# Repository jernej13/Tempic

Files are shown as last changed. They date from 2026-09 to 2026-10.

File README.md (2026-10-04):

# Tempic
Small 50mm x 50mm solar powered ESP32c6 based indoor/outdoor WiFi/Zigbee sensor node.

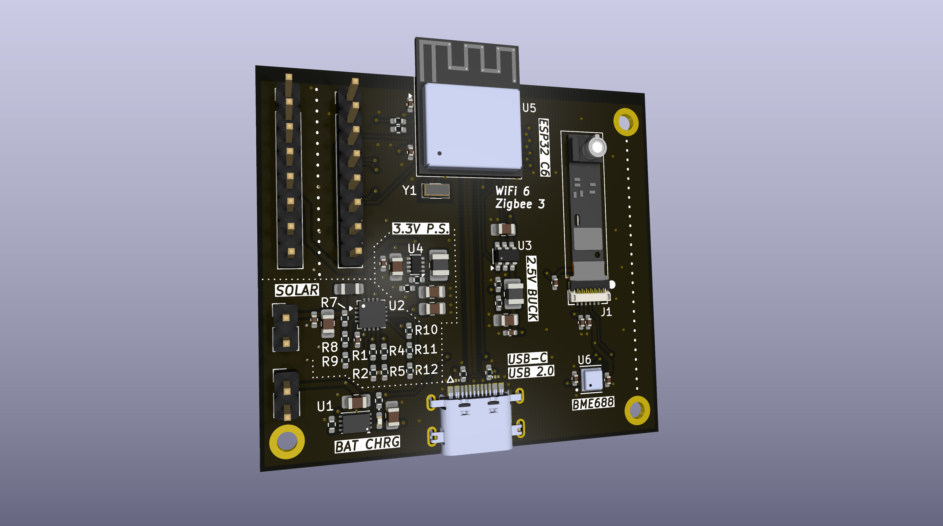
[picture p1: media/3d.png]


# Features
- Onboard ESP32 C6 mini with
    - WiFi 6 (2.4 GHz)
    - Zigbee 3
    - Bluetooth 5.3

- BME688
    - Temperature
    - Humidity
    - Pressure
    - CO2 
    
- BMV080 (for outdoor use)
    - P.M. 1.0
    - P.M. 2.5
    - P.M. 10

- Small 5x5cm solar panel
- Small 5x5cm LiPo battery

Goal is easy Home Assistant integration with unlimited battery life and cable-less deployment.
# Roadmap
- [x] Hardware 1.0
    - [x] Find suitable ICs
    - [x] Schematics 1.0
    - [x] Draw PCB 1.0
    - [x] Order prototype
    - [x] Assemble the PCB
    - [x] Test PCB
- [ ] Hardware 1.1
    - [ ] Fix current PCB mistakes
    - [ ] Order PCB
    - [ ] Assemble and test PCB
- [ ] Firmware
    - [x] Basic test and demo of sensors
    - [ ] Battery life optimization
    - [ ] Add Wifi
    - [ ] Setup connection to Home Assistant
    - [ ] Add Zigbee
    - [ ] (far) Add BLE peer to peer communication for bigger meshes
- [ ] Case
    - [ ] 3d design case
    - [ ] 3d print case  
- [ ] Home assistant
    - [ ] Figure out what is the best way to make it work (do not know if any custom plugins are necessary)
     
# Schematics
View [schematics](media/Schematics_1.0.pdf) in PDF format.

Developed in KiCad.

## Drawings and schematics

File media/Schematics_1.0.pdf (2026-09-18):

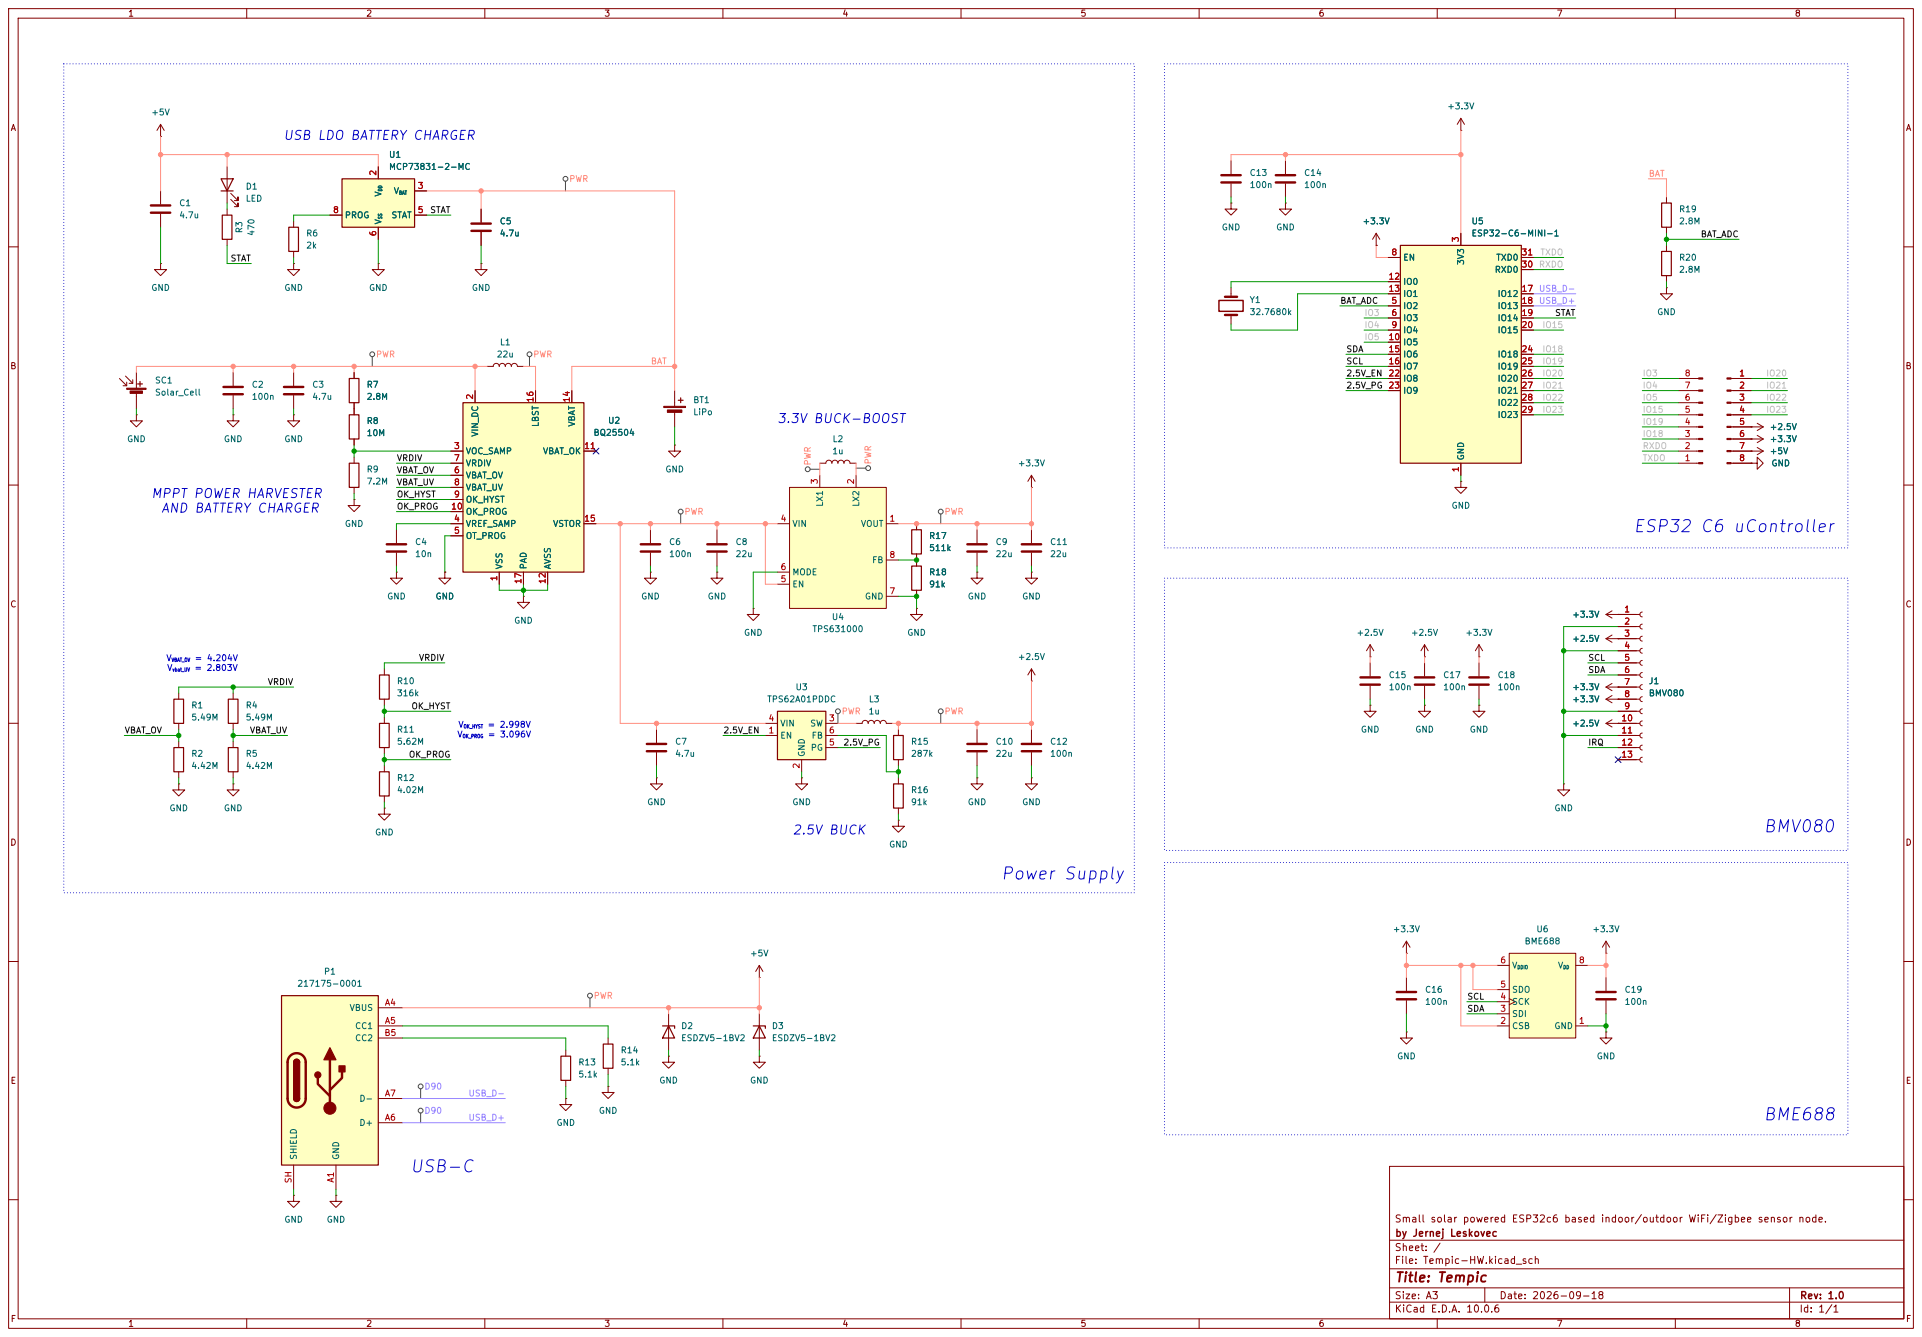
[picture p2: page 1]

VSTOR 15 LBST 16 PAD 17 GND

VREF_SAMP 4 OT_PROG 5

GND | 1 2 2 BMV080

Small solar powered ESP32c6 based indoor/outdoor WiFi/Zigbee sensor node.
by Jernej Leskovec
Sheet: /
File: Tempic-HW.kicad_sch
Title: Tempic

Size: A3 | Rev: 1.0 | F Date: 2026-09-18
KiCad E.D.A. 10.0.6 | Id: 1/1

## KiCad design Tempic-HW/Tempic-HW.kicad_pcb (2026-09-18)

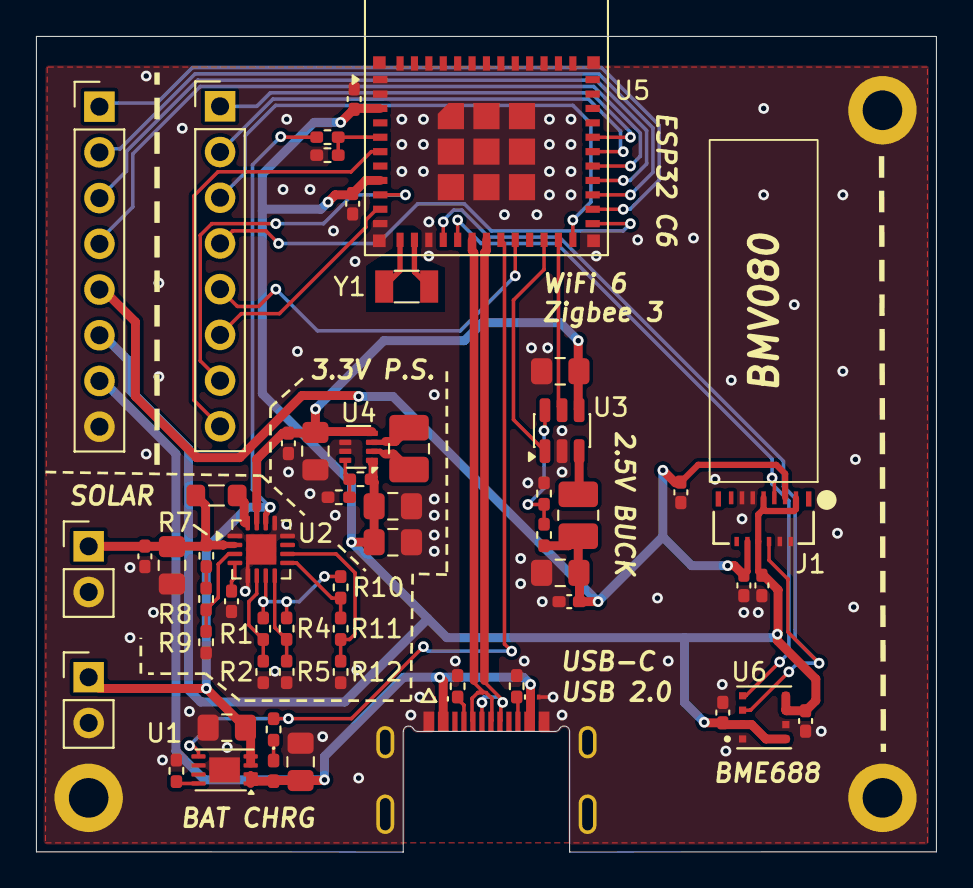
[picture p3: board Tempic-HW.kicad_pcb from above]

Board: 2 copper layers, 50.0 x 45.3 mm, 58 parts (0 on the bottom side), 47 nets.

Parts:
BT1: LiPo; PinHeader_1x02_P2.54mm_Vertical
C1, C3, C5, C7: 4.7u; C_0805_2012Metric_Pad1.18x1.45mm_HandSolder
C2, C6, C12, C13, C14, C15, C16, C17, C18, C19: 100n; C_0402_1005Metric_Pad0.74x0.62mm_HandSolder
C4: 10n; C_0402_1005Metric_Pad0.74x0.62mm_HandSolder
C8, C9, C10, C11: 22u; C_0805_2012Metric_Pad1.18x1.45mm_HandSolder
D1: LED; LED_0402_1005Metric_Pad0.77x0.64mm_HandSolder
D2, D3: ESDZV5-1BV2; Nexperia_DSN0603-2_0.6x0.3mm_P0.4mm
J1: BMV080; CON_5035661302_MOL
J2, J3: Conn_01x08_Pin; PinHeader_1x08_P2.54mm_Vertical
L1: 22u; L_0805_2012Metric_Pad1.05x1.20mm_HandSolder
L2, L3: 1u; L_1008_2520Metric_Pad1.43x2.20mm_HandSolder
P1: 217175-0001; MOLEX_2169900001
R1, R4: 5.49M; R_0402_1005Metric_Pad0.72x0.64mm_HandSolder
R2, R5: 4.42M; R_0402_1005Metric_Pad0.72x0.64mm_HandSolder
R3: 470; R_0402_1005Metric_Pad0.72x0.64mm_HandSolder
R6: 2k; R_0402_1005Metric_Pad0.72x0.64mm_HandSolder
R7, R19, R20: 2.8M; R_0402_1005Metric_Pad0.72x0.64mm_HandSolder
R8: 10M; R_0402_1005Metric_Pad0.72x0.64mm_HandSolder
R9: 7.2M; R_0402_1005Metric_Pad0.72x0.64mm_HandSolder
R10: 316k; R_0402_1005Metric_Pad0.72x0.64mm_HandSolder
R11: 5.62M; R_0402_1005Metric_Pad0.72x0.64mm_HandSolder
R12: 4.02M; R_0402_1005Metric_Pad0.72x0.64mm_HandSolder
R13, R14: 5.1k; R_0402_1005Metric_Pad0.72x0.64mm_HandSolder
R15: 287k; R_0402_1005Metric_Pad0.72x0.64mm_HandSolder
R16, R18: 91k; R_0402_1005Metric_Pad0.72x0.64mm_HandSolder
R17: 511k; R_0402_1005Metric_Pad0.72x0.64mm_HandSolder
SC1: Solar_Cell; PinHeader_1x02_P2.54mm_Vertical
U1: MCP73831-2-MC; DFN-8-1EP_3x2mm_P0.5mm_EP1.7x1.4mm
U2: BQ25504; VQFN-16-1EP_3x3mm_P0.5mm_EP1.68x1.68mm
U3: TPS62A01PDDC; SOT-23-6
U4: TPS631000; SOT-583-8
U5: ESP32-C6-MINI-1
U6: BME688
Y1: 32.7680k; Crystal_SMD_3215-2Pin_3.2x1.5mm

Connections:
+2.5V: C10.1, C12.1, C15.1, C17.1, J1.3, J1.10, J3.5, L3.2, R15.1
+3.3V: C9.1, C11.1, C13.1, C14.1, C16.1, C18.1, C19.1, J1.1, J1.7, J1.8, J3.6, R17.1, U4.1 (VOUT), U5.3 (3V3), U5.8 (EN), U6.2 (CSB), U6.5 (SDO), U6.6 (V_{DDIO}), U6.8 (V_{DD})
+5V: C1.1, D1.2 (A), D2.1 (K), D3.1 (K), J3.7, P1.A4 (VBUS), P1.A9 (VBUS), U1.1 (V_{DD}), U1.2 (V_{DD})
/2.5V_EN: U3.1 (EN), U5.22 (IO8)
/2.5V_PG: U3.5 (PG), U5.23 (IO9)
/BAT: BT1.1 (+), C5.1, R19.1, U1.3 (V_{BAT}), U1.4 (V_{BAT}), U2.14 (VBAT)
/BAT_ADC: R19.2, R20.1, U5.5 (IO2)
/IO3: J2.8, U5.6 (IO3)
/IO4: J2.7, U5.9 (IO4)
/IO5: J2.6, U5.10 (IO5)
/IO15: J2.5, U5.20 (IO15)
/IO18: J2.3, U5.24 (IO18)
/IO19: J2.4, U5.25 (IO19)
/IO20: J3.1, U5.26 (IO20)
/IO21: J3.2, U5.27 (IO21)
/IO22: J3.3, U5.28 (IO22)
/IO23: J3.4, U5.29 (IO23)
/OK_HYST: R10.2, R11.1, U2.9 (OK_HYST)
/OK_PROG: R11.2, R12.1, U2.10 (OK_PROG)
/RXDO: J2.2, U5.30 (RXD0)
/SCL: J1.5, U5.16 (IO7), U6.4 (SCK)
/SDA: J1.6, U5.15 (IO6), U6.3 (SDI)
/STAT: R3.2, U1.5 (STAT), U5.19 (IO14)
/TXDO: J2.1, U5.31 (TXD0)
/USB_D+: P1.A6 (D+), P1.B6 (D+), U5.18 (IO13)
/USB_D-: P1.A7 (D-), P1.B7 (D-), U5.17 (IO12)
/VBAT_OV: R1.2, R2.1, U2.6 (VBAT_OV)
/VBAT_UV: R4.2, R5.1, U2.8 (VBAT_UV)
/VRDIV: R1.1, R4.1, R10.1, U2.7 (VRDIV)
GND: BT1.2 (-), C1.2, C2.2, C3.2, C4.2, C5.2, C6.2, C7.2, C8.2, C9.2, C10.2, C11.2, C12.2, C13.2, C14.2, C15.2, C16.2, C17.2, C18.2, C19.2, D2.2 (A), D3.2 (A), J1.2, J1.4, J1.9, J1.11, J3.8, P1.A1 (GND), P1.A12 (GND), P1.SH (SHIELD), R2.2, R5.2, R6.2, R9.2, R12.2, R13.2, R14.2, R16.2, R18.2, R20.2, SC1.2 (-), U1.6 (V_{SS}), U1.9 (V_{SS}), U2.1 (VSS), U2.5 (OT_PROG), U2.12 (AVSS), U2.13 (VSS), U2.17 (PAD), U3.2 (GND), U4.6 (MODE), U4.7 (GND), U5.1 (GND), U5.2 (GND), U5.11 (GND), U5.14 (GND), U5.36 (GND), U5.37 (GND), U5.38 (GND), U5.39 (GND), U5.40 (GND), U5.41 (GND), U5.42 (GND), U5.43 (GND), U5.44 (GND), U5.45 (GND), U5.46 (GND), U5.47 (GND), U5.48 (GND), U5.49 (GND), U5.50 (GND), U5.51 (GND), U5.52 (GND), U5.53 (GND), U6.1 (GND), U6.7 (GND)
unnamed: D1.1 (K), R3.1
unnamed: P1.A5 (CC1), R14.1
unnamed: P1.B5 (CC2), R13.1
unnamed: R7.2, R8.1
unnamed: C2.1, C3.1, L1.1, R7.1, SC1.1 (+), U2.2 (VIN_DC)
unnamed: R6.1, U1.8 (PROG)
unnamed: L1.2, U2.16 (LBST)
unnamed: R8.2, R9.1, U2.3 (VOC_SAMP)
unnamed: C4.1, U2.4 (VREF_SAMP)
unnamed: C6.1, C7.1, C8.1, U2.15 (VSTOR), U3.4 (VIN), U4.4 (VIN), U4.5 (EN)
unnamed: R15.2, R16.1, U3.6 (FB)
unnamed: L3.1, U3.3 (SW)
unnamed: R17.2, R18.1, U4.8 (FB)
unnamed: L2.1, U4.3 (LX1)
unnamed: L2.2, U4.2 (LX2)
unnamed: U5.12 (IO0), Y1.1
unnamed: U5.13 (IO1), Y1.2

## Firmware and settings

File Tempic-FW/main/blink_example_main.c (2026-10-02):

#include "freertos/FreeRTOS.h"
#include "freertos/task.h"
#include "esp_log.h"
#include "driver/i2c_master.h"

#define TAG "BME688"
#define ADDR 0x77
#define SDA GPIO_NUM_6
#define SCL GPIO_NUM_7

static i2c_master_dev_handle_t dev;

static esp_err_t wr(uint8_t r, uint8_t v)
{
    uint8_t d[2] = {r, v};
    return i2c_master_transmit(dev, d, 2, 100);
}

static esp_err_t rd(uint8_t r, uint8_t *d, size_t n)
{
    return i2c_master_transmit_receive(dev, &r, 1, d, n, 100);
}

void app_main(void)
{
    i2c_master_bus_config_t bc = {
        .clk_source = I2C_CLK_SRC_DEFAULT,
        .i2c_port = I2C_NUM_0,
        .sda_io_num = SDA,
        .scl_io_num = SCL,
        .glitch_ignore_cnt = 7,
        .flags.enable_internal_pullup = true,
    };

    i2c_master_bus_handle_t bus;
    ESP_ERROR_CHECK(i2c_new_master_bus(&bc, &bus));

    i2c_device_config_t dc = {
        .dev_addr_length = I2C_ADDR_BIT_LEN_7,
        .device_address = ADDR,
        .scl_speed_hz = 100000,
    };

    ESP_ERROR_CHECK(i2c_master_bus_add_device(bus, &dc, &dev));

    /* Humidity oversampling x1 */
    ESP_ERROR_CHECK(wr(0x72, 0x01));

    /* Temperature/pressure x1 */
    ESP_ERROR_CHECK(wr(0x74, 0x25));

    while (1) {
        ESP_LOGI(TAG, "Starting measurement");

        /* Forced mode */
        ESP_ERROR_CHECK(wr(0x74, 0x25));

        /* Wait for measurement */
        vTaskDelay(pdMS_TO_TICKS(20));

        uint8_t status;

        if (rd(0x1D, &status, 1) != ESP_OK) {
            ESP_LOGE(TAG, "Status read failed");
            continue;
        }

        ESP_LOGI(TAG, "Status = 0x%02X", status);

        /* Read pressure */
        uint8_t p[3];
        if (rd(0x1F, p, 3) != ESP_OK) {
            ESP_LOGE(TAG, "Pressure read failed");
            continue;
        }

        uint32_t pressure =
            ((uint32_t)p[0] << 12) |
            ((uint32_t)p[1] << 4) |
            (p[2] >> 4);

        /* Read temperature */
        uint8_t t[3];
        if (rd(0x22, t, 3) != ESP_OK) {
            ESP_LOGE(TAG, "Temperature read failed");
            continue;
        }

        uint32_t temperature =
            ((uint32_t)t[0] << 12) |
            ((uint32_t)t[1] << 4) |
            (t[2] >> 4);

        /* Read humidity */
        uint8_t h[2];
        if (rd(0x25, h, 2) != ESP_OK) {
            ESP_LOGE(TAG, "Humidity read failed");
            continue;
        }

        uint16_t humidity =
            ((uint16_t)h[0] << 8) |
            h[1];

        ESP_LOGI(TAG, "RAW TEMP : %lu",
                 (unsigned long)temperature);

        ESP_LOGI(TAG, "RAW PRESS: %lu",
                 (unsigned long)pressure);

        ESP_LOGI(TAG, "RAW HUM  : %u",
                 humidity);

        ESP_LOGI(TAG, "----------------");

        vTaskDelay(pdMS_TO_TICKS(1000));
    }
}

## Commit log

2026-09-15 Started on concept and added some chips.
    [Tempic-HW.kicad_pcb, Tempic-HW.kicad_sch]
2026-09-17 Conencted all power and started on senortec and ESP32
2026-09-17 Finished schematics.
2026-09-17 Added footrpints, ESD diode and some graphics.
2026-09-17 Fiksed USB symbol and footprint, added 3d models, added second CC resistor.
    [Tempic-HW.kicad_pcb]
2026-09-18 Finished PCB, added silkscreen graphics.
    [Tempic-HW.kicad_pcb]
2026-09-18 Chandeg hysteresis of battery charging and edited README.
    [Tempic-HW.kicad_pcb]
2026-09-18 Changed one of the resistors and wrong value of USB
2026-09-18 Fixed PCB edge.
    [Tempic-HW.kicad_pcb]
2026-10-02 Soldered and started testing PCB, Power supplies are good, ESP is programmable via JTAG... and some additions and fixes to the PCB are needed.
    [blink_example_main.c]
2026-10-02 Soldered BME688 and Wrote some vibe coded code to test the BME688, and sensor works just fine.
